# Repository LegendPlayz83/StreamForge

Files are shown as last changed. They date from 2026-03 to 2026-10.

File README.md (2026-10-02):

# StreamForge
This is my keyboard design, which I made from scratch in KiCad and Fusion 360
Screenshot 2026-03-29 at 4 59 35 PM

Features:

- 108x Diodes
- 108x keys
- Raspberry Pi Pico
- Customised layout
- KMK firmware
  
### Schematic
newsch

### PCB 
Screenshot 2026-03-29 at 4 20 49 PM

### Case
Screenshot 2026-03-29 at 5 02 34 PM

### BOM

| Name | Quantity | Cost | Link |
|---|---|---|---|
| Akko Creamy Cyan | 108 | $30 | [Buy](https://stackskb.com/store/akko-creamy-cyan-switch-pack-of-45-pre-order/) |
| Durock Smokey Screw-In Stabilizers V2 (4+1 w/ 6.25u spacebar) | 1 | $18.58 | [Buy](https://stackskb.com/store/durock-smokey-screw-in-stabilizers-v2/) |
| Womier Azure Eclipse Side Backlit Cherry PBT Keycap | 1 | $27 | [Buy](https://curiositycaps.in/products/flow-backlit-side-printed-cherry-pbt-keycap-set) |
| Diode 1N4148 Through-Hole | 100 | $2.15 | [Buy](https://www.amazon.in/dp/B084ZP5BJ3) |
| PCB - (Black Color) | 5 | $66 | [Buy](https://order.lioncircuits.com/) |
| Raspberry Pi Pico | 1 | $7.40 | [Buy](https://www.amazon.in/Raspberry-Pi-Headers-Soldered-Micro/dp/B08WPNM7JB) |
| Heatset and Screws | 1 | $0.00 | Amazon |
| Case (top, mid, bot) | 1 | $0.00 | Printing Legion |
| **Total** | | **$151.13** | |

The total costs come out to be $152

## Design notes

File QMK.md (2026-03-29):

## Flashing & Configuring the Keyboard

Steps to install the firmware and configure the keyboard:-

### 1. Download the .uf2 file from repo
Download it and save it on your computer locally

### 2. Enter Boot Mode on the Pico
1. Unplug the Raspberry Pi Pico from your computer.
2. Hold down the **BOOTSEL** button on the Pico.
3. While holding the button, plug the Pico into your computer using a USB cable.
4. The computer will detect a new drive, namely **RPI-RP2**.

### 3. Flash the Firmware
1. Download the `.uf2` firmware file from this repo.
2. Drag and drop the file onto the **RPI-RP2** drive.

Once the file finishes copying, the Pico will reboot automatically.

### 5. Configure the Keymap
The keyboard layout can be customised in the .json file and keymap.c

Open the file in a text editor and edit the keymap section to match the layout.  
After saving the file, the keyboard will automatically reload with the new configuration.

### 6. Test the Keyboard
Unplug and reconnect the keyboard, open a text editor, and press some keys to make sure everything works.

KABOOMMMM 
ITS DONNEEE

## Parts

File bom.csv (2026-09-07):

Name | Quantity | Cost | Link
Akko Creamy Cyan | 108 | $30 | https://stackskb.com/store/akko-creamy-cyan-switch-pack-of-45-pre-order/
Durock Smokey Screw-In Stabilizers V2 (7+1 w/ 6.25u spacebar) | 1 | $18.58 | https://stackskb.com/store/durock-smokey-screw-in-stabilizers-v2/
Womier Azure Eclipse Side Backlit Cherry PBT Keycap | 1 | $27.00 | https://curiositycaps.in/products/flow-backlit-side-printed-cherry-pbt-keycap-set
Diode 1N4148 Through - Hole | 100 | $2.15 | https://www.amazon.in/dp/B084ZP5BJ3?ref_=cm_sw_r_cp_ud_dp_YPW3WFYTE31QA18570D1&_encoding=UTF8&psc=1
PCB - (Black Color) | 5 | $66 | https://jlcpcb.com/
Raspberry Pi Pico | 1 | $7.40 | https://amzn.in/d/4E8fnHk
Heatset and Screws | 1 | $0.00 | https://onlyscrews.in/
Case- top,mid,bot | 1 | $0.00 | Printing Legion

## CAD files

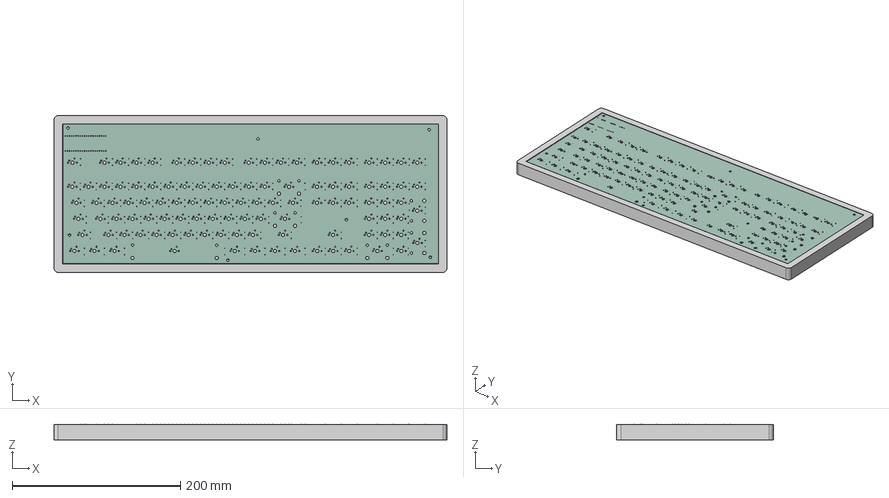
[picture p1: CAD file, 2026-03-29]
CAD/StreamForge-Full.step
466.7 x 186.3 x 18.4 mm
D_DO-35_SOD27_P7.62mm_Horizontal x 108
StreamForge_PCB

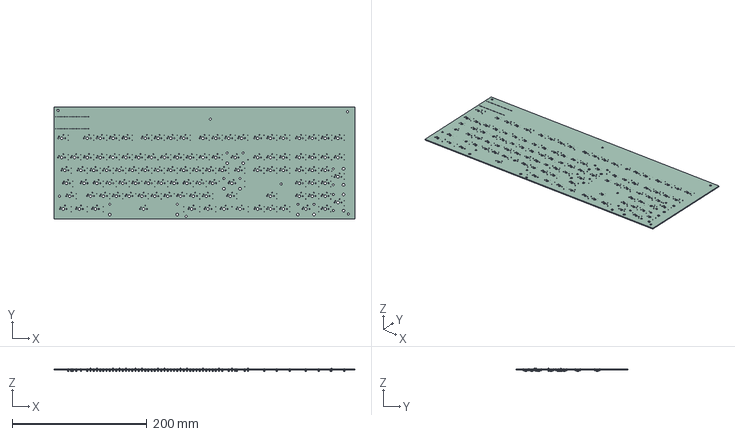
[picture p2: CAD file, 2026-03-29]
CAD/StreamForge-PCB.step
446.2 x 165.8 x 5.01 mm
D_DO-35_SOD27_P7.62mm_Horizontal x 108
StreamForge_PCB

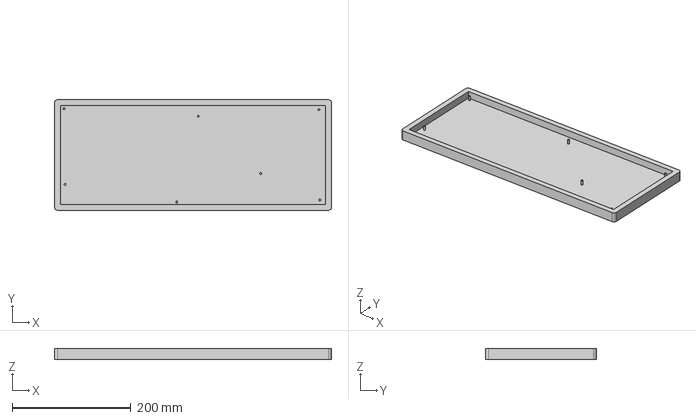
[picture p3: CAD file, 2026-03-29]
CAD/Streamforge-Case.step
466.7 x 186.3 x 18.0 mm

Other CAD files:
PCB/StreamForge.step
CAD/StreamForge-Full.f3z
CAD/Streamforge-Case.f3d

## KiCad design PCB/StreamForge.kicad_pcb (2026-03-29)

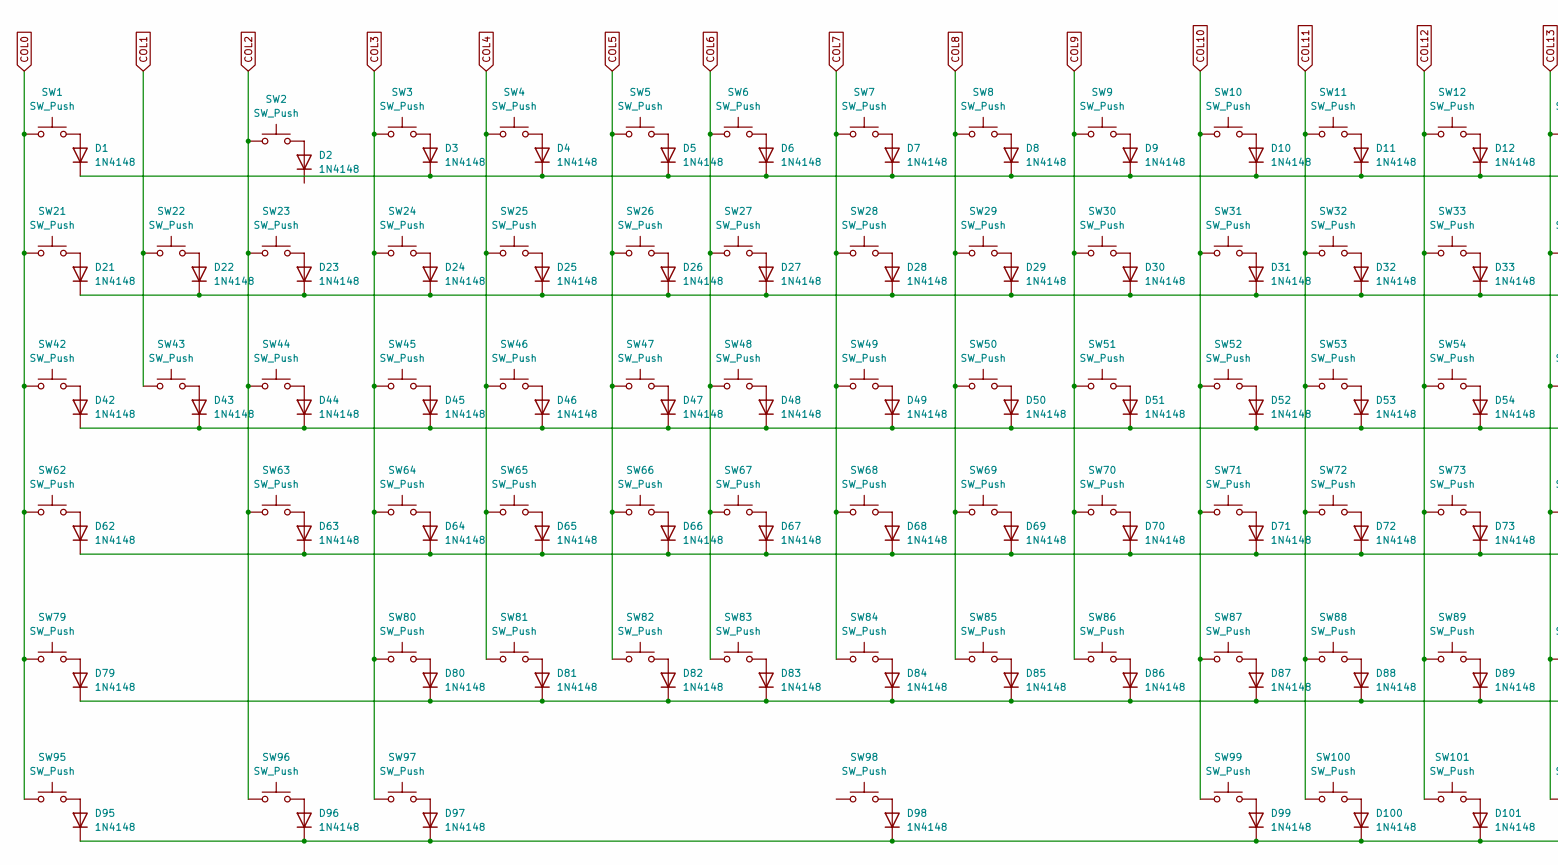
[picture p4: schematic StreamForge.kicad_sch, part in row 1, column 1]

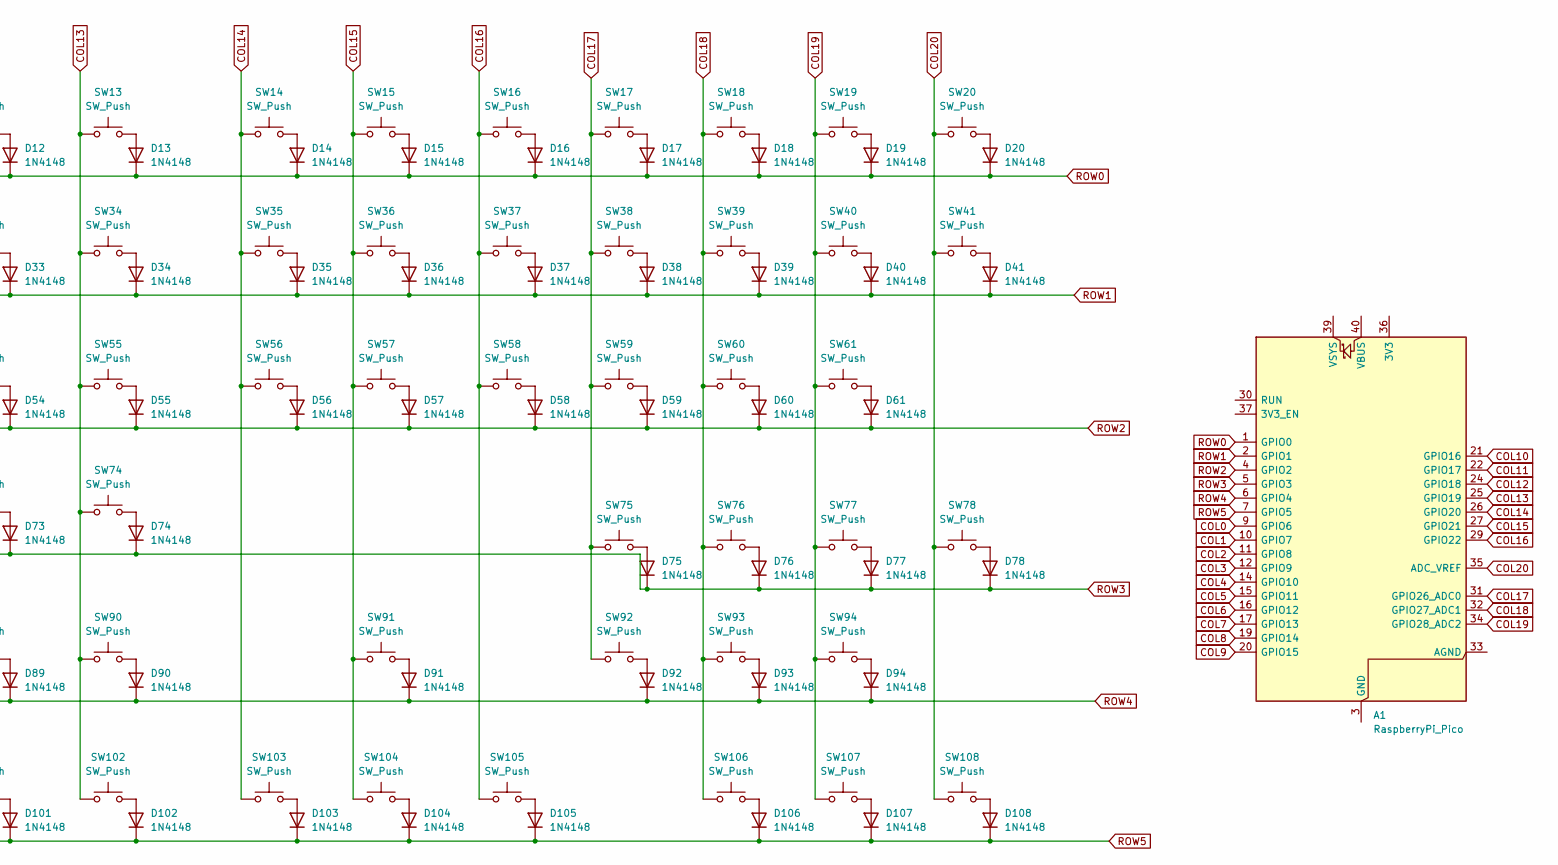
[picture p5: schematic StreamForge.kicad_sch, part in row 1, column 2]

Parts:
A1: RaspberryPi_Pico; RaspberryPi_Pico_Common_THT
D1, D2, D3, D4, D5, D6, D7, D8, D9, D10, D11, D12, D13, D14, D15, D16, D17, D18, D19, D20, D21, D22, D23, D24, D25, D26, D27, D28, D29, D30, D31, D32, D33, D34, D35, D36, D37, D38, D39, D40, D41, D42, D43, D44, D45, D46, D47, D48, D49, D50, D51, D52, D53, D54, D55, D56, D57, D58, D59, D60, D61, D62, D63, D64, D65, D66, D67, D68, D69, D70, D71, D72, D73, D74, D75, D76, D77, D78, D79, D80, D81, D82, D83, D84, D85, D86, D87, D88, D89, D90, D91, D92, D93, D94, D95, D96, D97, D98, D99, D100, D101, D102, D103, D104, D105, D106, D107, D108: 1N4148; D_DO-35_SOD27_P7.62mm_Horizontal
SW1, SW2, SW3, SW4, SW5, SW6, SW7, SW8, SW9, SW10, SW11, SW12, SW13, SW14, SW15, SW16, SW17, SW18, SW19, SW20, SW21, SW22, SW23, SW24, SW25, SW26, SW27, SW28, SW29, SW30, SW31, SW32, SW33, SW35, SW36, SW37, SW38, SW39, SW40, SW41, SW42, SW43, SW44, SW45, SW46, SW47, SW48, SW49, SW50, SW51, SW52, SW53, SW54, SW55, SW56, SW57, SW58, SW59, SW60, SW61, SW62, SW63, SW64, SW65, SW66, SW67, SW68, SW69, SW70, SW71, SW72, SW73, SW75, SW76, SW77, SW79, SW80, SW81, SW82, SW83, SW84, SW85, SW86, SW87, SW88, SW89, SW90, SW91, SW92, SW93, SW94, SW103, SW104, SW105, SW107: SW_Push; SW_Cherry_MX_1.00u_PCB
SW34, SW74, SW106: SW_Push; SW_Cherry_MX_2.00u_PCB
SW78, SW108: SW_Push; SW_Cherry_MX_2.00u_Vertical_PCB
SW95, SW96, SW97, SW99, SW100, SW101, SW102: SW_Push; SW_Cherry_MX_1.25u_PCB
SW98: SW_Push; SW_Cherry_MX_6.25u_PCB

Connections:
COL0: A1.9 (GPIO6), SW1.1, SW21.1, SW42.1, SW62.1, SW79.1, SW95.1
COL1: A1.10 (GPIO7), SW22.1, SW43.1
COL2: A1.11 (GPIO8), SW2.1, SW23.1, SW44.1, SW63.1, SW96.1
COL3: A1.12 (GPIO9), SW3.1, SW24.1, SW45.1, SW64.1, SW80.1, SW97.1
COL4: A1.14 (GPIO10), SW4.1, SW25.1, SW46.1, SW65.1, SW81.1
COL5: A1.15 (GPIO11), SW5.1, SW26.1, SW47.1, SW66.1, SW82.1
COL6: A1.16 (GPIO12), SW6.1, SW27.1, SW48.1, SW67.1, SW83.1
COL7: A1.17 (GPIO13), SW7.1, SW28.1, SW49.1, SW68.1, SW84.1
COL8: A1.19 (GPIO14), SW8.1, SW29.1, SW50.1, SW69.1, SW85.1
COL9: A1.20 (GPIO15), SW9.1, SW30.1, SW51.1, SW70.1, SW86.1
COL10: A1.21 (GPIO16), SW10.1, SW31.1, SW52.1, SW71.1, SW87.1, SW99.1
COL11: A1.22 (GPIO17), SW11.1, SW32.1, SW53.1, SW72.1, SW88.1, SW100.1
COL12: A1.24 (GPIO18), SW12.1, SW33.1, SW54.1, SW73.1, SW89.1, SW101.1
COL13: A1.25 (GPIO19), SW13.1, SW34.1, SW55.1, SW74.1, SW90.1, SW102.1
COL14: A1.26 (GPIO20), SW14.1, SW35.1, SW56.1, SW103.1
COL15: A1.27 (GPIO21), SW15.1, SW36.1, SW57.1, SW91.1, SW104.1
COL16: A1.29 (GPIO22), SW16.1, SW37.1, SW58.1, SW105.1
COL17: A1.31 (GPIO26_ADC0), SW17.1, SW38.1, SW59.1, SW75.1, SW92.1
COL18: A1.32 (GPIO27_ADC1), SW18.1, SW39.1, SW60.1, SW76.1, SW93.1, SW106.1
COL19: A1.34 (GPIO28_ADC2), SW19.1, SW40.1, SW61.1, SW77.1, SW94.1, SW107.1
COL20: A1.35 (ADC_VREF), SW20.1, SW41.1, SW78.1, SW108.1
unnamed: A1.3 (GND), A1.8 (GND), A1.13 (GND), A1.18 (GND), A1.23 (GND), A1.28 (GND), A1.38 (GND)
unnamed: D1.2 (A), SW1.2
unnamed: D2.2 (A), SW2.2
unnamed: D3.2 (A), SW3.2
unnamed: D4.2 (A), SW4.2
unnamed: D5.2 (A), SW5.2
unnamed: D6.2 (A), SW6.2
unnamed: D7.2 (A), SW7.2
unnamed: D8.2 (A), SW8.2
unnamed: D9.2 (A), SW9.2
unnamed: D10.2 (A), SW10.2
unnamed: D11.2 (A), SW11.2
unnamed: D12.2 (A), SW12.2
unnamed: D13.2 (A), SW13.2
unnamed: D14.2 (A), SW14.2
unnamed: D15.2 (A), SW15.2
unnamed: D16.2 (A), SW16.2
unnamed: D17.2 (A), SW17.2
unnamed: D18.2 (A), SW18.2
unnamed: D19.2 (A), SW19.2
unnamed: D20.2 (A), SW20.2
unnamed: D21.2 (A), SW21.2
unnamed: D22.2 (A), SW22.2
unnamed: D23.2 (A), SW23.2
unnamed: D24.2 (A), SW24.2
unnamed: D25.2 (A), SW25.2
unnamed: D26.2 (A), SW26.2
unnamed: D27.2 (A), SW27.2
unnamed: D28.2 (A), SW28.2
unnamed: D29.2 (A), SW29.2
unnamed: D30.2 (A), SW30.2
unnamed: D31.2 (A), SW31.2
unnamed: D32.2 (A), SW32.2
unnamed: D33.2 (A), SW33.2
unnamed: D34.2 (A), SW34.2
unnamed: D35.2 (A), SW35.2
unnamed: D36.2 (A), SW36.2
unnamed: D37.2 (A), SW37.2
unnamed: D38.2 (A), SW38.2
unnamed: D39.2 (A), SW39.2
unnamed: D40.2 (A), SW40.2
unnamed: D41.2 (A), SW41.2
unnamed: D42.2 (A), SW42.2
unnamed: D43.2 (A), SW43.2
unnamed: D44.2 (A), SW44.2
unnamed: D45.2 (A), SW45.2
unnamed: D46.2 (A), SW46.2
unnamed: D47.2 (A), SW47.2
unnamed: D48.2 (A), SW48.2
unnamed: D49.2 (A), SW49.2
unnamed: D50.2 (A), SW50.2
unnamed: D51.2 (A), SW51.2
unnamed: D52.2 (A), SW52.2
unnamed: D53.2 (A), SW53.2
unnamed: D54.2 (A), SW54.2
unnamed: D55.2 (A), SW55.2
unnamed: D56.2 (A), SW56.2
unnamed: D57.2 (A), SW57.2
unnamed: D58.2 (A), SW58.2
unnamed: D59.2 (A), SW59.2
unnamed: D60.2 (A), SW60.2
unnamed: D61.2 (A), SW61.2
unnamed: D62.2 (A), SW62.2
unnamed: D63.2 (A), SW63.2
unnamed: D64.2 (A), SW64.2
unnamed: D65.2 (A), SW65.2
unnamed: D66.2 (A), SW66.2
unnamed: D67.2 (A), SW67.2
unnamed: D68.2 (A), SW68.2
unnamed: D69.2 (A), SW69.2
unnamed: D70.2 (A), SW70.2
unnamed: D71.2 (A), SW71.2
unnamed: D72.2 (A), SW72.2
unnamed: D73.2 (A), SW73.2
unnamed: D74.2 (A), SW74.2
unnamed: D75.2 (A), SW75.2
unnamed: D76.2 (A), SW76.2
unnamed: D77.2 (A), SW77.2
unnamed: D78.2 (A), SW78.2
unnamed: D79.2 (A), SW79.2
unnamed: D80.2 (A), SW80.2
unnamed: D81.2 (A), SW81.2
unnamed: D82.2 (A), SW82.2
unnamed: D83.2 (A), SW83.2
unnamed: D84.2 (A), SW84.2
unnamed: D85.2 (A), SW85.2
unnamed: D86.2 (A), SW86.2
unnamed: D87.2 (A), SW87.2
unnamed: D88.2 (A), SW88.2
unnamed: D89.2 (A), SW89.2
unnamed: D90.2 (A), SW90.2
unnamed: D91.2 (A), SW91.2
unnamed: D92.2 (A), SW92.2
unnamed: D93.2 (A), SW93.2
unnamed: D94.2 (A), SW94.2
unnamed: D95.2 (A), SW95.2
unnamed: D96.2 (A), SW96.2
unnamed: D97.2 (A), SW97.2
unnamed: D98.2 (A), SW98.2
unnamed: D99.2 (A), SW99.2
unnamed: D100.2 (A), SW100.2
unnamed: D101.2 (A), SW101.2
unnamed: D102.2 (A), SW102.2
unnamed: D103.2 (A), SW103.2
unnamed: D104.2 (A), SW104.2
unnamed: D105.2 (A), SW105.2
unnamed: D106.2 (A), SW106.2
unnamed: D107.2 (A), SW107.2
unnamed: D108.2 (A), SW108.2
ROW0: A1.1 (GPIO0), D1.1 (K), D3.1 (K), D4.1 (K), D5.1 (K), D6.1 (K), D7.1 (K), D8.1 (K), D9.1 (K), D10.1 (K), D11.1 (K), D12.1 (K), D13.1 (K), D14.1 (K), D15.1 (K), D16.1 (K), D17.1 (K), D18.1 (K), D19.1 (K), D20.1 (K)
ROW1: A1.2 (GPIO1), D21.1 (K), D22.1 (K), D23.1 (K), D24.1 (K), D25.1 (K), D26.1 (K), D27.1 (K), D28.1 (K), D29.1 (K), D30.1 (K), D31.1 (K), D32.1 (K), D33.1 (K), D34.1 (K), D35.1 (K), D36.1 (K), D37.1 (K), D38.1 (K), D39.1 (K), D40.1 (K), D41.1 (K)
ROW2: A1.4 (GPIO2), D42.1 (K), D43.1 (K), D44.1 (K), D45.1 (K), D46.1 (K), D47.1 (K), D48.1 (K), D49.1 (K), D50.1 (K), D51.1 (K), D52.1 (K), D53.1 (K), D54.1 (K), D55.1 (K), D56.1 (K), D57.1 (K), D58.1 (K), D59.1 (K), D60.1 (K), D61.1 (K)
ROW3: A1.5 (GPIO3), D62.1 (K), D63.1 (K), D64.1 (K), D65.1 (K), D66.1 (K), D67.1 (K), D68.1 (K), D69.1 (K), D70.1 (K), D71.1 (K), D72.1 (K), D73.1 (K), D74.1 (K), D75.1 (K), D76.1 (K), D77.1 (K), D78.1 (K)
ROW4: A1.6 (GPIO4), D79.1 (K), D80.1 (K), D81.1 (K), D82.1 (K), D83.1 (K), D84.1 (K), D85.1 (K), D86.1 (K), D87.1 (K), D88.1 (K), D89.1 (K), D90.1 (K), D91.1 (K), D92.1 (K), D93.1 (K), D94.1 (K)
ROW5: A1.7 (GPIO5), D95.1 (K), D96.1 (K), D97.1 (K), D98.1 (K), D99.1 (K), D100.1 (K), D101.1 (K), D102.1 (K), D103.1 (K), D104.1 (K), D105.1 (K), D106.1 (K), D107.1 (K), D108.1 (K)

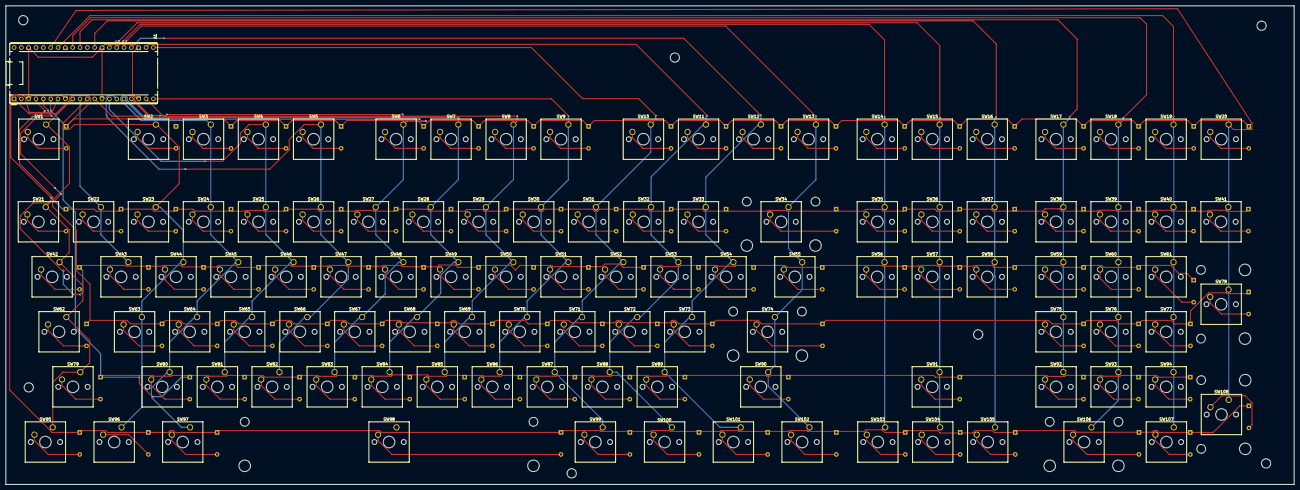
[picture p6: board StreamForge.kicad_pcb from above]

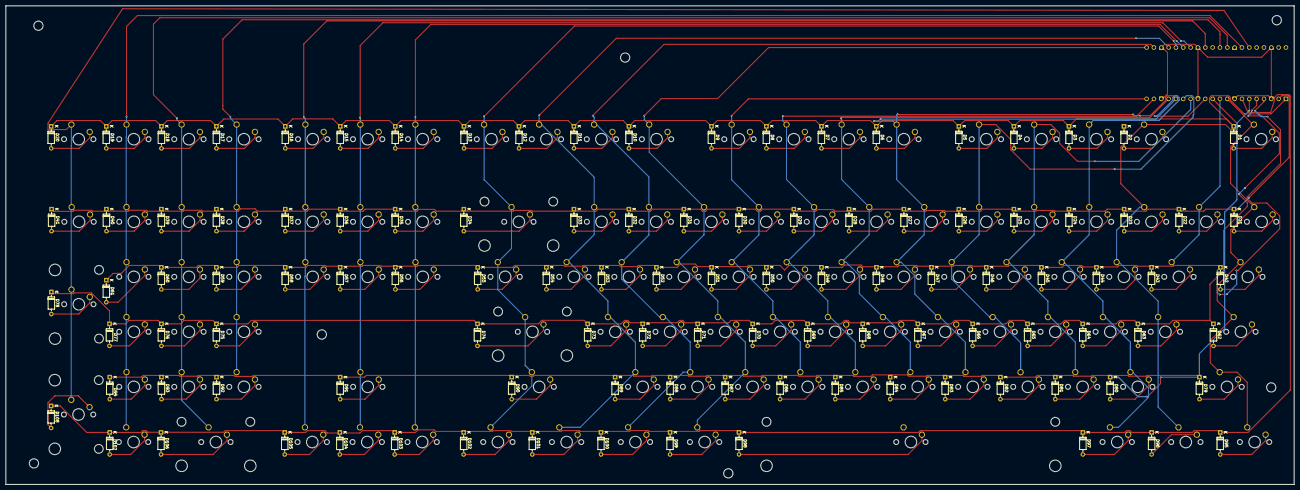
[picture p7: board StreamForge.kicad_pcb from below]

Board: 2 copper layers, 446.2 x 165.8 mm, 217 parts (108 on the bottom side), 136 nets.

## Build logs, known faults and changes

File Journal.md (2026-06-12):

# Streamforge

A 100% mechanical keyboard with 108 switches

# 2026-05-05: Case Designing Time!

**Total time spent: 3.2 hours**

Now that I am done with the PCB, I opened Fusion 360 and started making the case.



Extruding base by 5mm :



Extruding sides by 18mm:



Creating a sketch for the mounting towers:



Extruding the mounting towers:



Doing Fillet on Case edges:



Final look:



# 2026-05-05: Added holes for mounting the pcb to the case

**Total time spent: 0.25 hours**

I added 6-7(six-sevannnn) holes for mounting the PCB to the case since I don't like to hide the PCB beneath a plastic case. I am glad that the PCB work is done, and now I can move on to the case.

Screenshot 2026-04-06 at 4.33.49 PM

Screenshot 2026-04-06 at 4.34.04 PM

# 2026-05-05: Routing time!!!

**Total time spent: 3.4 hours**

In this session, I routed the 330 nets(to be precise), and this was sooo sooo fun but a lengthy task. You gotta change layers so many times, take different ways and more



Done with routing-

Screenshot 2026-04-05 at 12.17.25 PM

# 2026-05-05: Placed rest of components on PCB i.e. diodes and rp pico

**Total time spent: 3 hours**

After placing all the keys, I placed all the remaining 1N4148 diodes along with the rasp pi pico. It was such a boring and lengthy task to do. But hard work paid off!



Screenshot 2026-04-04 at 11.49.10 AM

# 2026-05-05: Placed all keys on PCB

**Total time spent: 3 hours**

In this session, I placed all the keys according to the layout, down to the last 6 millimetres, which was very boring and tiring work. I took 2-3 breaks in this work, but finally did it!


Final Work:


# 2026-05-05: Filled footprints for the symbols

**Total time spent: 0.05 hours**

In this session, I labelled all the keys according to the ansi 108 key keyboard layout. They were mostly 1.00u and1.25u, but some were different
Screenshot 2026-04-02 at 3.17.54 PM

Screenshot 2026-04-02 at 3.18.07 PM

Screenshot 2026-04-02 at 3.18.21 PM

Screenshot 2026-04-02 at 3.18.37 PM

Screenshot 2026-04-02 at 3.18.48 PM

Screenshot 2026-04-02 at 3.19.02 PM

Screenshot 2026-04-02 at 3.19.10 PM

# 2026-05-05: Placing symbols in schematic

**Total time spent: 2 hours**

Place all the symbols in the schematic according to the 108-key layout. I had several problems with layouts, so many versions, but I finalised the schematic after much thinking and work.


 
Had to use ADC_VREF coz I was out of GPIO pins
Screenshot 2026-04-01 at 7.54.25 PM

# 2026-05-05: Writing firmware

**Total time spent: 2.3 hours**

Wrote the firmware according to the matrix of the keeb and pin funcions. 
Screenshot 2026-06-12 at 5 21 33 PM

<h3>Please note, since i am importing this old unsubmitted project, the times are of same day</h3>

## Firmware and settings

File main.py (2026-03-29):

import board
from kmk.kmk_keyboard import KMKKeyboard
from kmk.keys import KC
from kmk.scanners.keypad import MatrixScanner
from kmk.modules.layers import Layers

keyboard = KMKKeyboard()

ROW_PINS = [
    board.GP0,
    board.GP1,
    board.GP2,
    board.GP3,
    board.GP4,
    board.GP5,
]

COL_PINS = [
    board.GP6,
    board.GP7,
    board.GP8,
    board.GP9,
    board.GP10,
    board.GP11,
    board.GP12,
    board.GP13,
    board.GP14,
    board.GP15,
    board.GP16,
    board.GP17,
    board.GP18,
    board.GP19,
    board.GP20,
    board.GP21,
    board.GP22,
    board.GP26,
    board.GP27,
    board.GP28,
]

keyboard.matrix = MatrixScanner(
    column_pins=COL_PINS,
    row_pins=ROW_PINS,
    columns_to_anodes=False,
)

keyboard.modules.append(Layers())

TRNS = KC.TRNS

keyboard.keymap = [
    [
        KC.ESC,  KC.F1,  KC.F2,  KC.F3,  KC.F4,  KC.F5,  KC.F6,  KC.F7,  KC.F8,
        KC.F9,  KC.F10, KC.F11, KC.F12,
        KC.PSCR, KC.SLCK, KC.PAUS,
        KC.INS,  KC.HOME, KC.PGUP, TRNS,

        KC.GRV,  KC.N1,  KC.N2,  KC.N3,  KC.N4,  KC.N5,  KC.N6,  KC.N7,  KC.N8,
        KC.N9,  KC.N0,  KC.MINS, KC.EQL, KC.BSPC,
        KC.DEL,  KC.END,  KC.PGDN,
        KC.NLCK, KC.PSLS, KC.PAST,

        KC.TAB,  KC.Q,   KC.W,   KC.E,   KC.R,   KC.T,   KC.Y,   KC.U,   KC.I,
        KC.O,   KC.P,   KC.LBRC, KC.RBRC, KC.BSLS,
        KC.P7,  KC.P8,  KC.P9,  KC.PMNS,

        KC.CAPS, KC.A,   KC.S,   KC.D,   KC.F,   KC.G,   KC.H,   KC.J,   KC.K,
        KC.L,   KC.SCLN, KC.QUOT, KC.ENT, TRNS,
        KC.P4,  KC.P5,  KC.P6,  KC.PPLS,

        KC.LSFT, TRNS,  KC.Z,   KC.X,   KC.C,   KC.V,   KC.B,   KC.N,   KC.M,
        KC.COMM, KC.DOT, KC.SLSH, KC.RSFT, KC.UP,
        KC.P1,  KC.P2,  KC.P3,  KC.PENT,

        KC.LCTL, KC.LGUI, KC.LALT, KC.SPC,  TRNS,   TRNS,   TRNS,   TRNS,
        KC.RALT, KC.RGUI, KC.APP,  KC.RCTL,
        KC.LEFT, KC.DOWN, KC.RGHT,
        KC.P0,  KC.PDOT, TRNS,
    ],
]

if __name__ == '__main__':
    keyboard.go()
